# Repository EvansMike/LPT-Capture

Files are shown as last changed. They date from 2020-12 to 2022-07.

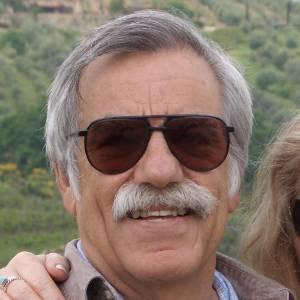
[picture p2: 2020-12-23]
doc/Read data from parallel port_files/floresta.jpeg

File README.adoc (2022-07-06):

= LPT Capture

Capture text from a parallel port to a file, then convert that to a LibreOffice document. Assumes that the format is plain text.

This was written to capture the parallel print output from a Megger used for PAT.  It will likely work for other legacy devices with parallel LPT ports.

This consists of hardware/firmware in /firmware and PC, Linux, software in /userware.

Micro controller code is C AVR not Arduino.  To make the firmware:

[source, bash]
cd firmware
make install

To build and install.  Edit the Makefile for your favourite installer tool.

First build your device using the schematic.

I used perf-board and wires since the wiring is very simple.  Resistor values are 1K but other values around this may work too.
No resistors at all will also work but may expose your parallel port to currents it can's handle.
There should probably be voltage spike protection too with suitable diodes and/or a buffer chip. 

Compile the pc side utility with:

[source, bash]
cd userware
make install

== How to Use

- Plug it in to the port you want to capture from and a USB cable.
- Press Print on the device, a Megger AV4 in my case.  It should wait until a printer becomes attached
- Do:

[source, bash]
lpt_capture /dev/ttyUSB0 report.fodt

Command line arguments are input port and output file name.

Then don't open the output file.

Or rather use the LPT.log file as the  printfile.fodt wil be empty because this doesn't work
and I can't remember why anymore.

////[source, bash]
////libreoffice printfile.fodt

To open the file in LibreOffice Writer.
Or you can do all that mouse clicky malarky in your GUI.

Enjoy.  Also post bugs and improvements.

This was really a one off for some specific data I need to liberate.
I need to make it more generic.

Maybe.

I guess this could realistically convert direct to PDF but using LibreOffice to check and edit the output
is a useful intermediate step.  LibreOffice can do the conversion directly with:

[source, bash]
libreoffice7.0 --headless --convert-to pdf printfile.fodt

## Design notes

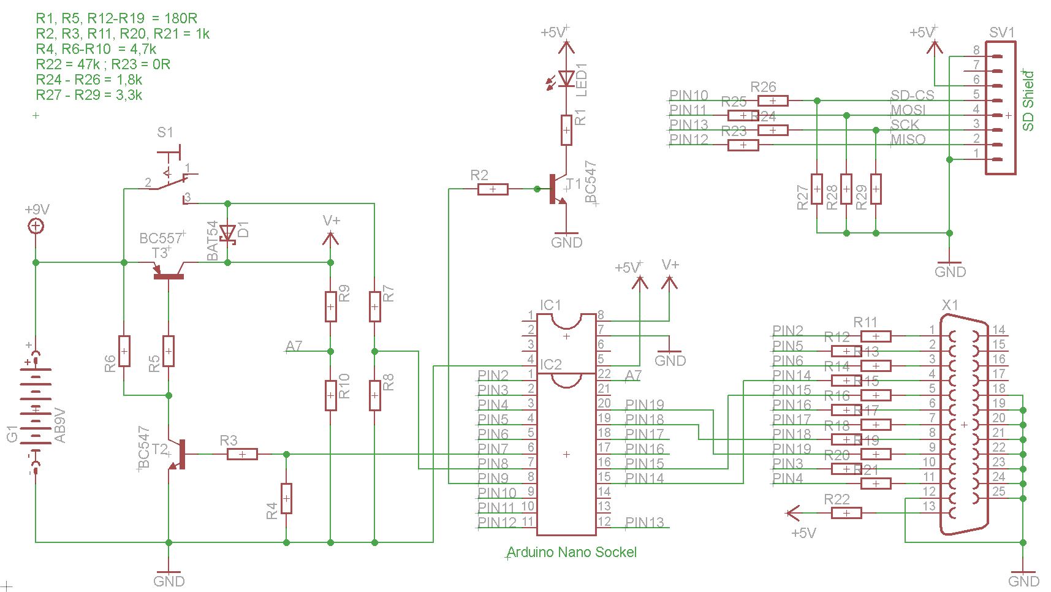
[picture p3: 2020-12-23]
doc/nano parallel port capture schematic.JPG

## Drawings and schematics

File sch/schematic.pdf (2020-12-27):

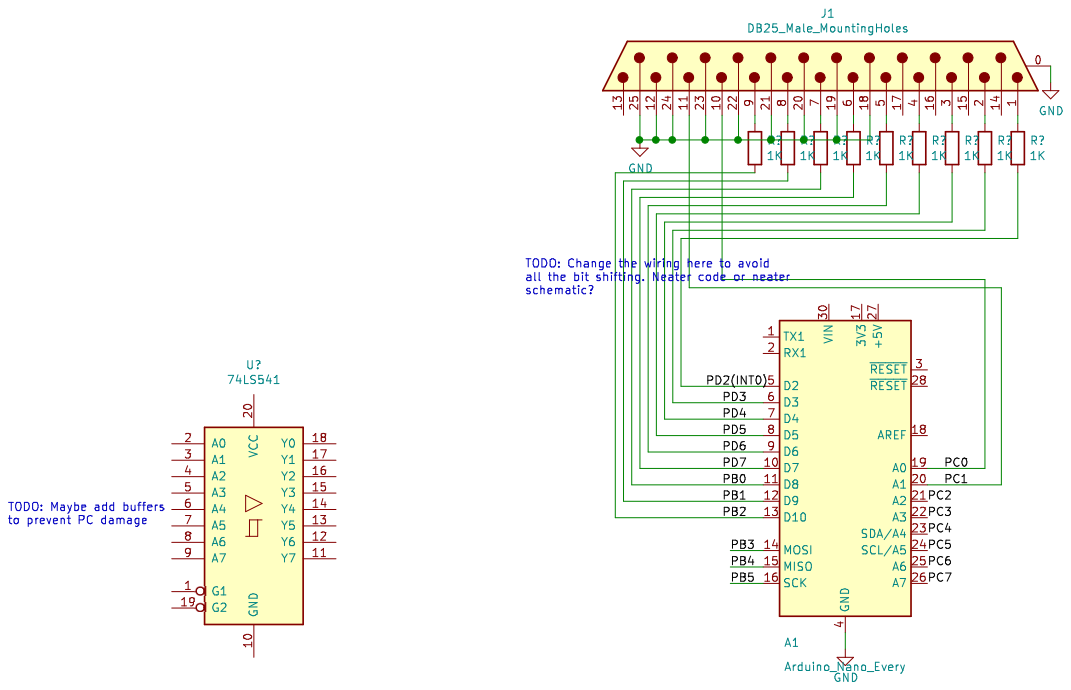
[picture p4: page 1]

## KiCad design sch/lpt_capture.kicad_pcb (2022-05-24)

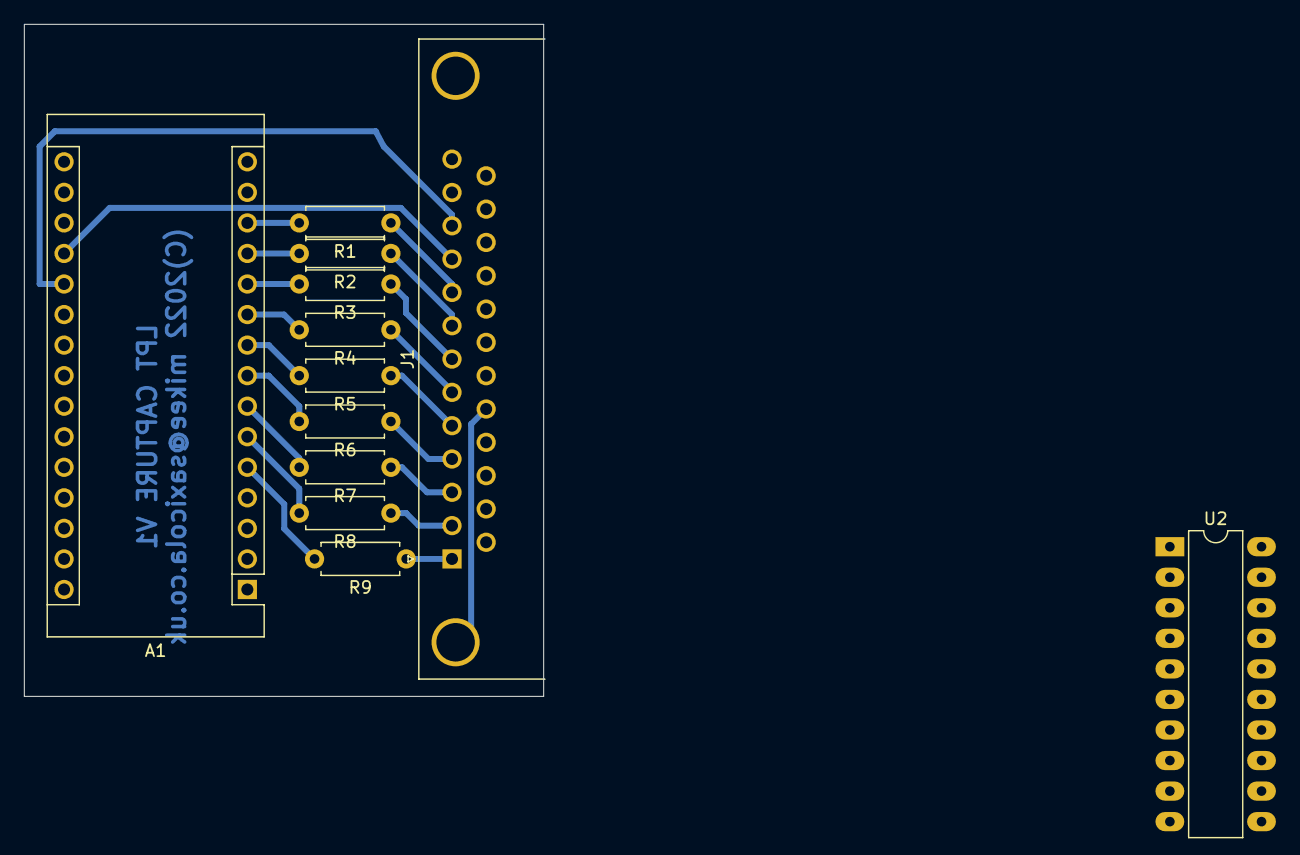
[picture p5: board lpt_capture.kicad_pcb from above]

Board: 2 copper layers, 43.2 x 55.9 mm, 12 parts (0 on the bottom side), 21 nets.

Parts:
A1: Arduino_Nano_Every; Arduino_Nano
J1: DB25_Male_MountingHoles; DSUB-25_Male_Horizontal_P2.77x2.84mm_EdgePinOffset4.94mm_Ho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
R1, R2, R3, R4, R5, R6, R7, R8, R9: 1K; R_Axial_DIN0207_L6.3mm_D2.5mm_P7.62mm_Horizontal
U2: 74LS541; DIP-20_W7.62mm_LongPads

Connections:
/PB0: A1.11, R3.2
/PB1: A1.12, R2.2
/PB2: A1.13, R1.2
/PC0: A1.19, J1.10
/PC1: A1.20, J1.11
/PD2(INT0): A1.5, R9.2
/PD3: A1.6, R8.2
/PD4: A1.7, R7.2
/PD5: A1.8, R6.2
/PD6: A1.9, R5.2
/PD7: A1.10, R4.2
GND: A1.4, A1.29, J1.0, J1.12, J1.18, J1.19, J1.20, J1.21, J1.22, J1.23, J1.24, J1.25
unnamed: J1.1, R9.1
unnamed: J1.2, R8.1
unnamed: J1.3, R7.1
unnamed: J1.4, R6.1
unnamed: J1.5, R5.1
unnamed: J1.6, R4.1
unnamed: J1.7, R3.1
unnamed: J1.8, R2.1
unnamed: J1.9, R1.1

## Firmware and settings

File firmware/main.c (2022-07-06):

/*
 * main.c
 *
 * Copyright 2020 Mike Evans <mikee@saxicola.co.uk>
 *
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
 *
 * ------------------
 * Wiring Layout
 * -------------
 *
 * Parallel Port Output               Mega168 Pins                  UNO pins
 * --------------------               -------------
 * Name      Dir.   Pin                Name     Pin
 * ----      ----   ---                ----     ---
 * nSTROBE    >       1................INT0     PD2 (INT0)
 * DATA BYTE  >     2-9....................
 * nACK       <      10....................     3
 * BUSY       <      11....................     4
 * OutofPaper <      12................GND
 * Selected   <      13.................5v
 * GND        <>  18-25................GND
 *-------------------------------------------------------------------------------
 *
 * CS:      pin 10
 * MOSI:    pin 11
 * MISO:    pin 12
 * SCK:     pin 13
 *
 ********************************************************************************/


#include <stdio.h>
#include <avr/io.h>
#include <avr/sfr_defs.h>
#include <util/delay.h>
#include <avr/interrupt.h>
#include <stdlib.h>
#include <avr/pgmspace.h>
#include <avr/eeprom.h>
#include "gitversion.h"
//#include "serial.h"
#include <string.h>
#include <time.h>

#define nStrobe PD2 // To INT0 pin
#define nAck    PC0 //
#define busy    PC1 //
#define LED     PB5

enum States {
  READY,
  BUSY,
  ACK,
  STDBY,
  TXEND
} state;



/*
Set to 9600 8 N 1
*/
static void USART_Init ()
{
  #define BAUD 38400
  #include <util/setbaud.h>
  UBRR0H = UBRRH_VALUE;
  UBRR0L = UBRRL_VALUE;
  UCSR0C = 0x06;       /* Set frame format: 8data, 1stop bit  */
  UCSR0B = (1<<TXEN0); /* Enable  transmitter                 */
}


static void USART_Transmit (unsigned char data)
{
/* Wait for empty transmit buffer */
while (!(UCSR0A & (1<<UDRE0)));
/* Put data into buffer, sends the data */
UDR0 = data;
}


static void USART_Tx_string(char * string)
{
  while( *string )
  {
    USART_Transmit( *string++ );
  }
}

/***********************************************************************
Interrupt to detect nStrobe
 **********************************************************************/
ISR(INT0_vect)
{
    state = BUSY;
    cli();
}


/***********************************************************************
 * MAIN YAAYYYY
 *
 **********************************************************************/
int main()
{
    DDRC |= _BV(nAck) | _BV(busy);
    unsigned char data;
    uint32_t timeout_count = 0;
    USART_Init ();
    state = READY;
    EIMSK |= _BV(INT0);
    EICRA |= _BV(ISC11); // Trigger on falling edge
    PORTC |= _BV(nStrobe) | _BV(busy); // Pull these UP
    PORTD |= _BV(PD2); // Pull UP

    sei();

    USART_Tx_string("Hello World\n");


    while(1)
    {
        //timeout_count ++;
        //if(timeout_count == 0) state = TXEND;
        switch (state) {
        case READY:
          timeout_count = 1;
          //digitalWrite(Busy, LOW);
          PORTC &= ~_BV(busy);
          //digitalWrite(nAck,HIGH);
          PORTC |= _BV(nAck);
          //digitalWrite(led, HIGH);
          PORTB |= _BV(LED); // ON
          sei();
          break;
        case BUSY: // nStrobe signal received by interrupt handler
          timeout_count = 1;
          //digitalWrite(Busy, HIGH);
          PORTC |= _BV(busy);
          //digitalWrite(led, LOW);
          PORTB &= ~_BV(LED); // OFF
          data = 0;
          data = ((PIND & 0b11111000) >> 3) | ((PINB & 0b00000111) << 5) ;
          USART_Transmit(data);
          state = ACK;
          break;
        case ACK:
          timeout_count = 1;
          //digitalWrite(nAck,LOW);
          PORTC &= ~_BV(nAck);
          _delay_us(5); //milliseconds. Specification minimum = 5 us
          state = READY;

          break;
        case STDBY:
          break;
        case TXEND: // Transmit EOF zero
          USART_Transmit('\0');
          timeout_count = 1;
          break;
        }
    }
while(1);
}

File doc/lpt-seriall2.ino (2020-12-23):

/********************************************************************************
 * PrinterCaptureInterrupt.ino
 * ------------------
 * Monitor a parallel port printer output and capture each character. Output the
 * character on the USB serial port so it can be captured in a terminal program.
 *
 * By............: Paul Jewell
 * Date..........: 29th January 2015
 * Version.......: 0.1a
 * Modification : Change Interrupt Routine so Arduino respond "faster" to Printer
 *                Writing Busy Signal directly from interrupt routine
 *                Ecirbaf 12 Jan 2017
 *                Test on a PC with a "generic Printer Text only" printer
 *                Printing a test page OK
 *                Even if using somme accent characters
 *                Depend How your Terminal Software is handling that.
 *-------------------------------------------------------------------------------
 * Wiring Layout
 * -------------
 *
 * Parallel Port Output               Arduino Input
 * --------------------               -------------
 * Name      Dir.   Pin                Name    Pin
 * ----      ----   ---                ----    ---
 * nSTROBE    >       1................INT0      2 (as interupt)
 * DATA BYTE  >     2-9.......................3-10   
 * nACK       <      10.........................11
 * BUSY       <      11.........................12
 * OutofPaper <      12................GND
 * Selected   <      13.................5v
 * GND        <>  18-25................GND
 *-------------------------------------------------------------------------------
 ********************************************************************************/

int nStrobe = 2;
int Data0   = 3;
int Data1   = 4;
int Data2   = 5;
int Data3   = 6;
int Data4   = 7;
int Data5   = 8;
int Data6   = 9;
int Data7   = 10;
int nAck    = 11;
int Busy    = 12;
int led     = 13; // use as status led

enum States {
  READY,
  BUSY,
  ACK
} State;

 

void setup()
{
  // Configure pins
  pinMode(nStrobe, INPUT_PULLUP);
 
  for (int n = Data0; n < (Data7+1); n++)
    pinMode(n, INPUT_PULLUP);
 
  pinMode(nAck, OUTPUT);
  pinMode(Busy, OUTPUT);
  pinMode(led, OUTPUT);
 
  Serial.begin(38400);    // ** Actual com port could at least go this speed  ** //
  while (!Serial) {
    ;
  }
 

 attachInterrupt(0,Interrupt,FALLING);  // ** Name :Interrupt,  was clearer for me than DataReady  ** //


  State = READY;
  delay(100);
  Serial.println("Initialised");
}

void loop()
{
  switch (State) {
    case READY:
      digitalWrite(Busy, LOW);
      digitalWrite(nAck,HIGH);
      digitalWrite(led, HIGH);
      break;
     
  //    case BUSY: // nStrobe signal received by interrupt handler
  //      digitalWrite(Busy, HIGH);
  //      digitalWrite(led, LOW);
  //      ProcessChar();
  //      State = ACK;
  //      break;
  // ** All this case is made during Interrupt (Avoid some missed characters with "fast" printer) **
 
    case ACK:
      digitalWrite(nAck,LOW);
      delay(1); //milliseconds. Specification minimum = 5 us    ** Reduced to 1 is ok **
      State = READY;
      break;
  }   
}

void Interrupt()
{
    digitalWrite(Busy, HIGH);
    digitalWrite(led, LOW);
    ProcessChar();
    State = ACK;
}

void ProcessChar()
{
  byte Char;
 
  Char = digitalRead(Data0) +
         (digitalRead(Data1) << 1) +
         (digitalRead(Data2) << 2) +
         (digitalRead(Data3) << 3) +
         (digitalRead(Data4) << 4) +
         (digitalRead(Data5) << 5) +
         (digitalRead(Data6) << 6) +
         (digitalRead(Data7) << 7);
         
  Serial.print((char)Char);
}

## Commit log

2020-12-23 Add IO pin control
2020-12-24 New PCB files.
    [lpt_capture.kicad_pcb, lpt_capture.sch]
2020-12-24 Print test good.
2020-12-27 Add 1K resistors and a note to schematic.
    [lpt_capture.kicad_pcb, lpt_capture.sch]
2020-12-27 Add REAL port names to schematic.
    [lpt_capture.sch]
2020-12-27 Add schematic pdf. new file: ../sch/schematic.pdf
2022-05-24 Do the PCB.
    [lpt_capture.kicad_pcb, lpt_capture.sch]
2022-05-24 Notes edit.
    [lpt_capture.sch]
2022-07-05 Fix pointer ‘fid’ used after ‘fclose’ [-Wuse-after-free]
2022-07-06 Extend timeout for slow printer.
2022-07-06 Shorten delay in ACK.
    [main.c]

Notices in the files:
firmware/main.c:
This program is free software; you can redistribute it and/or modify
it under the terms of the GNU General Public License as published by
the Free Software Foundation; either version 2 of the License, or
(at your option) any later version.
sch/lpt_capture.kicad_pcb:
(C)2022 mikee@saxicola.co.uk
